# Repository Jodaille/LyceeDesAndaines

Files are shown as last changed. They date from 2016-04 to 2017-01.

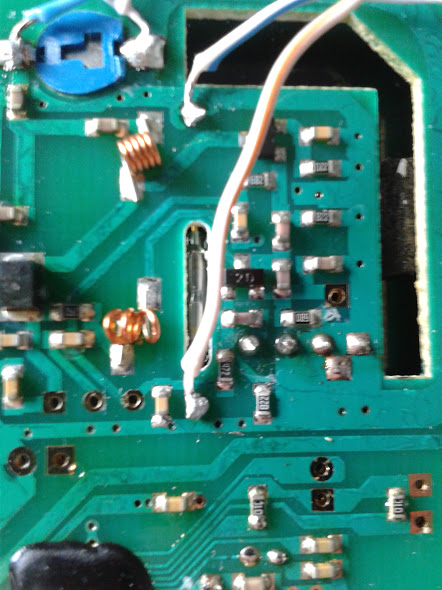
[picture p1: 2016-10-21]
JaugePluieInterruption/Soldered_wires_for_contact.jpg

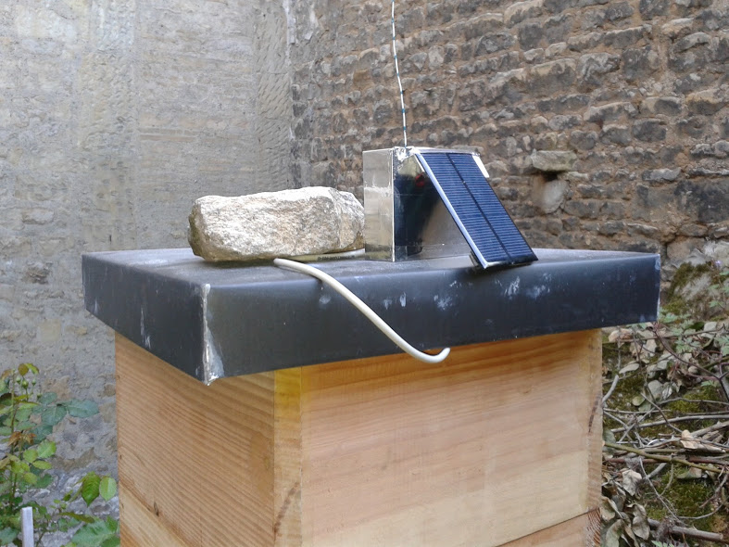
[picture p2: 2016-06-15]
Arduino_RF_mini_Solar_panel.jpg

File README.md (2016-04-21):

# Lycee Des Andaines

L'objectif est de connaître l'environnement extérieur et intérieur d'une ruche.

L'idée est de pouvoir anticiper au possible l'essaimage.

Arduino est choisi afin d'initier les élèves au développement logiciel,
à l'électricité, à l'électronique et à la mesure physique.

## Sketchs/programmes exemples

Nous avons besoin de connaître quelques facteurs environnementaux :

- température
- masse de la ruche
- activité de la ruche

Nous disposons de capteurs de type DS18B20.

La masse est estimée avec un capteur mesurant la pression exercée par la ruche
sur un liquide contenu dans des sachets étanches (type compote).

L'activité globale sera estimée à l'aide de capteurs infra-rouge placés
à l'entrée de la ruche.

## Difficultés (techniques) rencontrées

### Capteur de température

Thermomètre numérique DS18B20, version waterproof,
avec interface 1-Wire (One-wire).

### Compteur d'abeilles

Le compteur nécessite deux capteurs IR par couloir. (QRE1113 FSC SENSOR REFL 5MM PHOTOTRANS THRU)
Nous devons comparer le passage devant un capteur puis l'autre pour déduire s'il
s'agit d'une entrée ou d'une sortie.

La lecture des capteurs est assez rapide, elle effectue de nombreuses lectures
par secondes.

Pour une prote de ruche de près de 30cm, avec un couloir de 1cm de large, il
nous faudrait donc 60 capteurs IR.

Nous décidones de réduire cette porte, toutefois Arduino ne possède toujours
pas assez d'entrée. Nous décidons d'utiliser un/des multiplexeurs du type :
CD74HC4067

### Capteur de pression / mesure de l' évolution de la masse de la ruche

La précision du convertisseur ADC de l'Arduino est insuffisante,
nous décidons d'utiliser un convertisseur Analogique/Numérique ADS1015
avec une précision sur 12 bit à 3300 samples/seconde via I2C.

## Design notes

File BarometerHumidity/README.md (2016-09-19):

# Moniteur/enregistreur de l'environement de la ruche

Un Arduino Nano permet de relever la température, l'humidité extérieure,
la pression atmosphérique aux alentours de la ruche.

Deux capteurs de température DS18B20, un fixé au plancher devant
la porte d'entrée, l'autre sous le toit entre la grille et le couvre toit.

En attendant de pouvoir mesurer la hauteur des précipitations,
un capteur de chute de pluie est en test.

La plupart des capteurs sont reliés sur le bus I2C, correspondant
aux pins A4 et A5.

## Baromètre.

BMP 280 relié en I2C

## Température et humidité

Si7021 relié en I2C

## Capteur de chute de pluie

relié en A7

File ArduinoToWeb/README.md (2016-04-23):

# Connect Arduino to the Web with OpenWRT

## Requirements

- [x] Arduino Uno, Nano ...
- [x] OpenWRT Router [TL-WR703N Mod 64Mb](http://www.ebay.com/itm/181078954797)
- [x] a Webserver or a service

## Arduino talks to the Web

Arduino is linked to router by USB cable.

Read datas are written to serial (USB),
we use a [script](https://github.com/Jodaille/LyceeDesAndaines/blob/master/ArduinoToLinux/ReadArduinoSerial.sh) to read serial
port, do some string management, then play an HTTP GET query to a simple PHP script page on a remote server.

The script is launched on the router in a screen (GNU/Screen). So that process should not die when we kill current terminal session.

## Arduino test sketch

[LogTestToWeb.ino](https://github.com/Jodaille/LyceeDesAndaines/blob/master/ArduinoToLinux/LogTestToWeb/LogTestToWeb.ino) is a simple sketch that read then print some values every "interval" seconds (no delay) on the serial.

Each values are semicolumn separated.

## SHell script to read serial and push to the Web

[ReadArduinoSerial.sh](https://github.com/Jodaille/LyceeDesAndaines/blob/master/ArduinoToLinux/ReadArduinoSerial.sh) is launched on device /dev/ttyUSB0 (Nano)

## OpenWRT

Kernel modules to install, example:

    opkg update
    opkg install kmod-usb-serial-ch341

Modules for Arduino Nano with CH341 USB serial chip:

    kmod-usb-serial
    kmod-usb-serial-ch341
    kmod-usb-serial-cp210x

Tool to install:

    opkg install screen

[readUSB.sh](https://github.com/Jodaille/LyceeDesAndaines/blob/master/ArduinoToLinux/readUSB.sh) is a simple script that send output of serial port (/dev/ttyUSB0) to [ReadArduinoSerial.sh](https://github.com/Jodaille/LyceeDesAndaines/blob/master/ArduinoToLinux/ReadArduinoSerial.sh) for processing.

With screen you can have this process forever, that means it will not ended after your logout from terminal.

    screen -Sdm readArduino -s  /readUSB.sh

Next step will be to be able to start after the boot (crontab ?) and maybe to check that process exist unless relaunch it.

It could be nice if readUSB.sh could be detect the Arduino port.

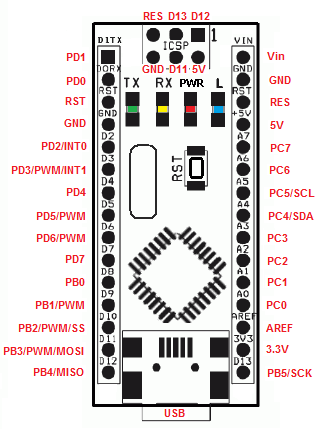
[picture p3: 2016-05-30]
ArduinoNano_pinout.png

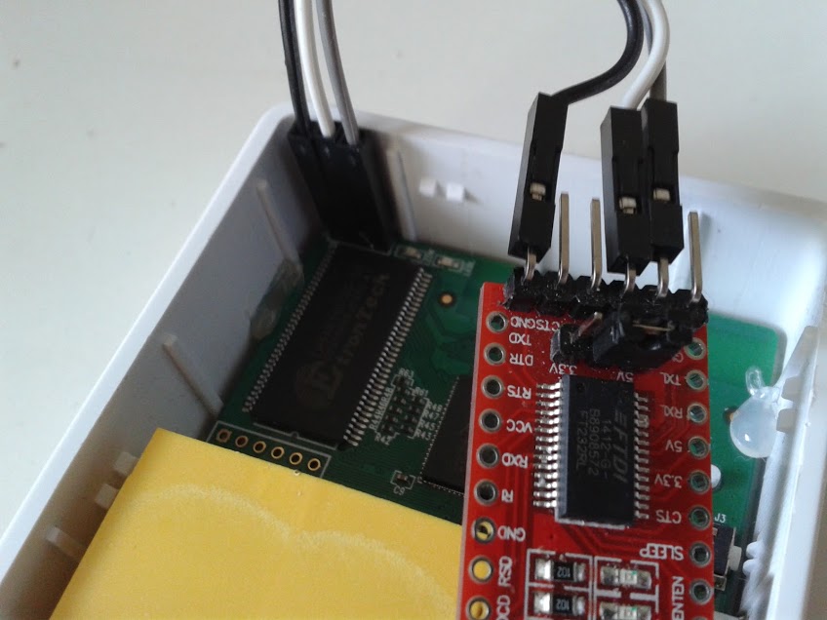
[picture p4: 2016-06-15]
GLiNet_FTDI_serial.jpg

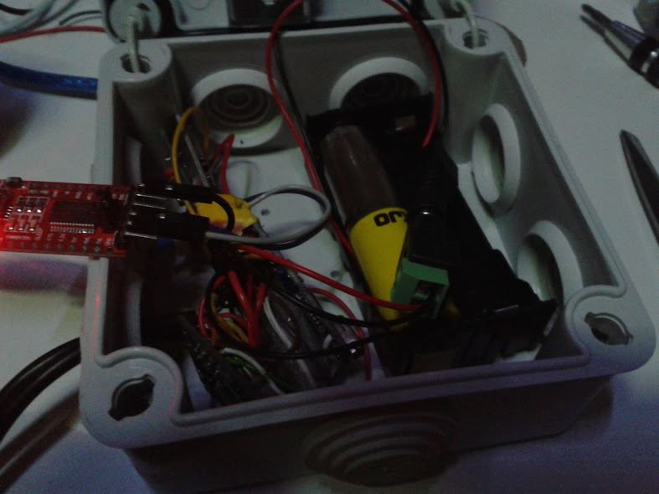
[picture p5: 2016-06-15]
Arduino_Logger.jpg

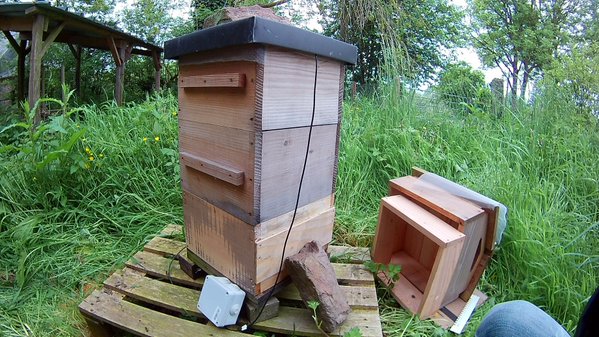
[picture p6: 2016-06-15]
Boitier_etanche.jpg

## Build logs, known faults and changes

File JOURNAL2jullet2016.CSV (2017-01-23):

id=13 | time=2016-06-25 16:50:09 | t1=17.94 | t2=18.88 | v=153 | milli=1414
id=13 | time=2016-06-25 16:50:41 | t1=18.06 | t2=19.13 | v=163 | milli=32332
id=13 | time=2016-06-25 16:51:12 | t1=18.19 | t2=19.44 | v=163 | milli=63223
id=13 | time=2016-06-25 16:51:43 | t1=18.81 | t2=19.94 | v=163 | milli=94112
id=13 | time=2016-06-25 16:52:15 | t1=19.56 | t2=20.88 | v=163 | milli=125002
id=13 | time=2016-06-25 16:52:46 | t1=19.81 | t2=21.06 | v=163 | milli=155892
id=13 | time=2016-06-25 16:53:18 | t1=19.88 | t2=21.13 | v=163 | milli=186784
id=13 | time=2016-06-25 16:53:49 | t1=19.94 | t2=21.06 | v=163 | milli=217675
id=13 | time=2016-06-25 16:54:20 | t1=19.94 | t2=21.00 | v=163 | milli=248570
id=13 | time=2016-06-25 16:54:52 | t1=19.94 | t2=20.88 | v=163 | milli=279462
id=13 | time=2016-06-25 16:55:23 | t1=20.00 | t2=20.81 | v=163 | milli=310353
id=13 | time=2016-06-25 16:55:55 | t1=20.13 | t2=20.75 | v=163 | milli=341244
id=13 | time=2016-06-25 16:56:26 | t1=20.25 | t2=20.69 | v=163 | milli=372133
id=13 | time=2016-06-25 16:56:58 | t1=20.44 | t2=20.63 | v=163 | milli=403025
id=13 | time=2016-06-25 16:57:29 | t1=20.56 | t2=20.63 | v=163 | milli=433916
id=13 | time=2016-06-25 16:58:00 | t1=20.63 | t2=20.44 | v=163 | milli=464811
id=13 | time=2016-06-25 16:58:32 | t1=20.69 | t2=20.38 | v=163 | milli=495702
id=13 | time=2016-06-25 16:59:03 | t1=20.69 | t2=20.25 | v=163 | milli=526594
id=13 | time=2016-06-25 16:59:35 | t1=20.63 | t2=20.13 | v=163 | milli=557484
id=13 | time=2016-06-25 17:00:06 | t1=20.63 | t2=20.06 | v=163 | milli=588374
id=13 | time=2016-06-25 17:00:37 | t1=20.63 | t2=19.94 | v=163 | milli=619265
id=13 | time=2016-06-25 17:01:09 | t1=20.56 | t2=19.81 | v=163 | milli=650157
id=13 | time=2016-06-25 17:01:40 | t1=20.50 | t2=19.75 | v=163 | milli=681047
id=13 | time=2016-06-25 17:02:12 | t1=20.50 | t2=19.63 | v=163 | milli=711943
id=13 | time=2016-06-25 17:02:43 | t1=20.44 | t2=19.50 | v=163 | milli=742834
id=13 | time=2016-06-25 17:03:15 | t1=20.38 | t2=19.38 | v=163 | milli=773725
id=13 | time=2016-06-25 17:03:46 | t1=20.38 | t2=19.25 | v=163 | milli=804614
id=13 | time=2016-06-25 17:04:17 | t1=20.38 | t2=19.19 | v=163 | milli=835506
id=13 | time=2016-06-25 17:04:49 | t1=20.25 | t2=19.13 | v=163 | milli=866397
id=13 | time=2016-06-25 17:05:20 | t1=20.25 | t2=19.13 | v=163 | milli=897288
id=13 | time=2016-06-25 17:05:52 | t1=20.25 | t2=19.13 | v=163 | milli=928183
id=13 | time=2016-06-25 17:06:23 | t1=20.25 | t2=19.00 | v=163 | milli=959075
id=13 | time=2016-06-25 17:06:54 | t1=20.31 | t2=18.88 | v=163 | milli=989965
id=13 | time=2016-06-25 17:07:26 | t1=20.31 | t2=18.88 | v=163 | milli=1020856
id=13 | time=2016-06-25 17:07:57 | t1=20.25 | t2=19.00 | v=163 | milli=1051748
id=13 | time=2016-06-25 17:08:29 | t1=20.19 | t2=19.06 | v=163 | milli=1082641
id=13 | time=2016-06-25 17:09:00 | t1=20.13 | t2=19.19 | v=163 | milli=1113533
id=13 | time=2016-06-25 17:09:32 | t1=20.19 | t2=19.38 | v=163 | milli=1144429
id=13 | time=2016-06-25 17:10:03 | t1=20.13 | t2=19.56 | v=163 | milli=1175322
id=13 | time=2016-06-25 17:10:34 | t1=20.06 | t2=19.63 | v=163 | milli=1206213
id=13 | time=2016-06-25 17:11:06 | t1=20.06 | t2=19.69 | v=163 | milli=1237104
id=13 | time=2016-06-25 17:11:37 | t1=20.13 | t2=19.69 | v=163 | milli=1267996
id=13 | time=2016-06-25 17:12:09 | t1=20.13 | t2=19.81 | v=163 | milli=1298889
id=13 | time=2016-06-25 17:12:40 | t1=20.13 | t2=19.81 | v=163 | milli=1329780
id=13 | time=2016-06-25 17:13:11 | t1=20.19 | t2=19.88 | v=163 | milli=1360677
id=13 | time=2016-06-25 17:13:43 | t1=20.19 | t2=19.81 | v=163 | milli=1391570
id=13 | time=2016-06-25 17:14:14 | t1=20.25 | t2=19.88 | v=163 | milli=1422461
id=13 | time=2016-06-25 17:14:46 | t1=20.25 | t2=19.81 | v=163 | milli=1453353
id=13 | time=2016-06-25 17:15:17 | t1=20.25 | t2=19.75 | v=163 | milli=1484244
id=13 | time=2016-06-25 17:15:48 | t1=20.25 | t2=19.75 | v=163 | milli=1515137
id=13 | time=2016-06-25 17:16:20 | t1=20.25 | t2=19.69 | v=163 | milli=1546028
id=13 | time=2016-06-25 17:16:51 | t1=20.25 | t2=19.56 | v=163 | milli=1576920
id=13 | time=2016-06-25 17:17:23 | t1=20.25 | t2=19.56 | v=163 | milli=1607817
id=13 | time=2016-06-25 17:17:54 | t1=20.25 | t2=19.50 | v=163 | milli=1638709
id=13 | time=2016-06-25 17:18:26 | t1=20.19 | t2=19.44 | v=163 | milli=1669599
id=13 | time=2016-06-25 17:18:57 | t1=20.19 | t2=19.38 | v=163 | milli=1700492
id=13 | time=2016-06-25 17:19:28 | t1=20.13 | t2=19.31 | v=163 | milli=1731384
id=13 | time=2016-06-25 17:20:00 | t1=20.06 | t2=19.19 | v=163 | milli=1762276
id=13 | time=2016-06-25 17:20:31 | t1=20.00 | t2=19.13 | v=163 | milli=1793168
id=13 | time=2016-06-25 17:21:03 | t1=20.00 | t2=19.13 | v=163 | milli=1824078
id=13 | time=2016-06-25 17:21:34 | t1=20.00 | t2=19.06 | v=163 | milli=1854972
id=13 | time=2016-06-25 17:22:05 | t1=20.00 | t2=19.00 | v=163 | milli=1885867
id=13 | time=2016-06-25 17:22:37 | t1=20.00 | t2=18.94 | v=163 | milli=1916761
id=13 | time=2016-06-25 17:23:08 | t1=20.00 | t2=18.81 | v=163 | milli=1947657
id=13 | time=2016-06-25 17:23:40 | t1=20.00 | t2=18.75 | v=163 | milli=1978550
id=13 | time=2016-06-25 17:24:11 | t1=20.00 | t2=18.69 | v=163 | milli=2009445
id=13 | time=2016-06-25 17:24:43 | t1=19.94 | t2=18.63 | v=163 | milli=2040345
id=13 | time=2016-06-25 17:25:14 | t1=19.94 | t2=18.56 | v=163 | milli=2071239
id=13 | time=2016-06-25 17:25:45 | t1=20.00 | t2=18.56 | v=163 | milli=2102133
id=13 | time=2016-06-25 17:26:17 | t1=20.00 | t2=18.50 | v=163 | milli=2133028
id=13 | time=2016-06-25 17:26:48 | t1=20.06 | t2=18.44 | v=163 | milli=2163923
id=13 | time=2016-06-25 17:27:20 | t1=20.00 | t2=18.38 | v=163 | milli=2194818
id=13 | time=2016-06-25 17:27:51 | t1=20.00 | t2=18.38 | v=163 | milli=2225711
id=13 | time=2016-06-25 17:28:22 | t1=19.94 | t2=18.38 | v=163 | milli=2256612
id=13 | time=2016-06-25 17:28:54 | t1=19.88 | t2=18.38 | v=163 | milli=2287506
id=13 | time=2016-06-25 17:29:25 | t1=19.81 | t2=18.31 | v=163 | milli=2318399
id=13 | time=2016-06-25 17:29:57 | t1=19.81 | t2=18.31 | v=163 | milli=2349295
id=13 | time=2016-06-25 17:30:28 | t1=19.75 | t2=18.31 | v=163 | milli=2380190
id=13 | time=2016-06-25 17:30:59 | t1=19.69 | t2=18.25 | v=163 | milli=2411084
id=13 | time=2016-06-25 17:31:31 | t1=19.69 | t2=18.25 | v=163 | milli=2441977
id=13 | time=2016-06-25 17:32:02 | t1=19.63 | t2=18.19 | v=163 | milli=2472878
id=13 | time=2016-06-25 17:32:34 | t1=19.56 | t2=18.19 | v=163 | milli=2503773
id=13 | time=2016-06-25 17:33:05 | t1=19.56 | t2=18.19 | v=163 | milli=2534666
id=13 | time=2016-06-25 17:33:36 | t1=19.50 | t2=18.19 | v=163 | milli=2565561
id=13 | time=2016-06-25 17:34:08 | t1=19.44 | t2=18.19 | v=163 | milli=2596457
id=13 | time=2016-06-25 17:34:39 | t1=19.44 | t2=18.19 | v=163 | milli=2627350
id=13 | time=2016-06-25 17:35:11 | t1=19.38 | t2=18.13 | v=163 | milli=2658245
id=13 | time=2016-06-25 17:35:42 | t1=19.38 | t2=18.06 | v=163 | milli=2689139
id=13 | time=2016-06-25 17:36:13 | t1=19.31 | t2=18.06 | v=163 | milli=2720039
id=13 | time=2016-06-25 17:36:45 | t1=19.31 | t2=18.00 | v=163 | milli=2750942
id=13 | time=2016-06-25 17:37:16 | t1=19.31 | t2=18.00 | v=163 | milli=2781836
id=13 | time=2016-06-25 17:37:48 | t1=19.25 | t2=17.94 | v=163 | milli=2812732
id=13 | time=2016-06-25 17:38:19 | t1=19.31 | t2=18.00 | v=163 | milli=2843626
id=13 | time=2016-06-25 17:38:50 | t1=19.44 | t2=18.00 | v=163 | milli=2874519
id=13 | time=2016-06-25 17:39:22 | t1=19.50 | t2=18.00 | v=163 | milli=2905415
id=13 | time=2016-06-25 17:39:53 | t1=19.44 | t2=18.06 | v=163 | milli=2936315
id=13 | time=2016-06-25 17:40:25 | t1=19.31 | t2=18.06 | v=163 | milli=2967208
id=13 | time=2016-06-25 17:40:56 | t1=19.25 | t2=18.06 | v=163 | milli=2998103
id=13 | time=2016-06-25 17:41:27 | t1=19.25 | t2=18.06 | v=163 | milli=3028998
id=13 | time=2016-06-25 17:41:59 | t1=19.19 | t2=18.13 | v=163 | milli=3059893
id=13 | time=2016-06-25 17:42:30 | t1=19.19 | t2=18.06 | v=163 | milli=3090786
id=13 | time=2016-06-25 17:43:02 | t1=19.13 | t2=18.06 | v=163 | milli=3121681
id=13 | time=2016-06-25 17:43:33 | t1=19.13 | t2=18.06 | v=163 | milli=3152581
id=13 | time=2016-06-25 17:44:04 | t1=19.13 | t2=18.00 | v=163 | milli=3183475
id=13 | time=2016-06-25 17:44:36 | t1=19.13 | t2=17.94 | v=163 | milli=3214370
id=13 | time=2016-06-25 17:45:07 | t1=19.13 | t2=17.94 | v=163 | milli=3245266
id=13 | time=2016-06-25 17:45:39 | t1=19.13 | t2=17.88 | v=163 | milli=3276159
id=13 | time=2016-06-25 17:46:10 | t1=19.19 | t2=17.88 | v=163 | milli=3307053
id=13 | time=2016-06-25 17:46:41 | t1=19.13 | t2=17.88 | v=163 | milli=3337948
id=13 | time=2016-06-25 17:47:13 | t1=19.06 | t2=17.88 | v=163 | milli=3368848
id=13 | time=2016-06-25 17:47:44 | t1=19.00 | t2=17.88 | v=163 | milli=3399742
id=13 | time=2016-06-25 17:48:16 | t1=19.00 | t2=17.81 | v=163 | milli=3430636
id=13 | time=2016-06-25 17:48:47 | t1=18.94 | t2=17.81 | v=163 | milli=3461532
id=13 | time=2016-06-25 17:49:18 | t1=18.94 | t2=17.88 | v=163 | milli=3492425
id=13 | time=2016-06-25 17:49:50 | t1=18.94 | t2=17.81 | v=163 | milli=3523319
id=13 | time=2016-06-25 17:50:21 | t1=18.94 | t2=17.81 | v=163 | milli=3554215
id=13 | time=2016-06-25 17:50:53 | t1=18.94 | t2=17.81 | v=163 | milli=3585129
id=13 | time=2016-06-25 17:51:24 | t1=18.88 | t2=17.81 | v=163 | milli=3616022
id=13 | time=2016-06-25 17:51:55 | t1=18.94 | t2=17.88 | v=163 | milli=3646929
id=13 | time=2016-06-25 17:52:27 | t1=18.94 | t2=17.88 | v=163 | milli=3677824
id=13 | time=2016-06-25 17:52:58 | t1=18.94 | t2=17.88 | v=163 | milli=3708718
id=13 | time=2016-06-25 17:53:30 | t1=18.88 | t2=17.94 | v=163 | milli=3739612
id=13 | time=2016-06-25 17:54:01 | t1=18.88 | t2=18.00 | v=163 | milli=3770507
id=13 | time=2016-06-25 17:54:32 | t1=18.88 | t2=18.06 | v=163 | milli=3801402
id=13 | time=2016-06-25 17:55:04 | t1=18.88 | t2=18.13 | v=163 | milli=3832301
id=13 | time=2016-06-25 17:55:35 | t1=18.81 | t2=18.19 | v=163 | milli=3863196
id=13 | time=2016-06-25 17:56:07 | t1=18.81 | t2=18.25 | v=163 | milli=3894091
id=13 | time=2016-06-25 17:56:38 | t1=18.81 | t2=18.38 | v=163 | milli=3924985
id=13 | time=2016-06-25 17:57:09 | t1=18.81 | t2=18.50 | v=163 | milli=3955879
id=13 | time=2016-06-25 17:57:41 | t1=18.81 | t2=18.63 | v=163 | milli=3986775
id=13 | time=2016-06-25 17:58:12 | t1=18.81 | t2=18.69 | v=163 | milli=4017669
id=13 | time=2016-06-25 17:58:44 | t1=18.81 | t2=18.75 | v=163 | milli=4048568
id=13 | time=2016-06-25 17:59:15 | t1=18.81 | t2=18.81 | v=163 | milli=4079463
id=13 | time=2016-06-25 17:59:47 | t1=18.81 | t2=18.81 | v=163 | milli=4110358
id=13 | time=2016-06-25 18:00:18 | t1=18.81 | t2=18.88 | v=163 | milli=4141253
id=13 | time=2016-06-25 18:00:49 | t1=18.81 | t2=18.88 | v=163 | milli=4172146
id=13 | time=2016-06-25 18:01:21 | t1=18.75 | t2=18.88 | v=163 | milli=4203042
id=13 | time=2016-06-25 18:01:52 | t1=18.81 | t2=18.88 | v=163 | milli=4233937
id=13 | time=2016-06-25 18:02:24 | t1=18.81 | t2=18.88 | v=163 | milli=4264835
id=13 | time=2016-06-25 18:02:55 | t1=18.81 | t2=18.88 | v=163 | milli=4295731
id=13 | time=2016-06-25 18:03:26 | t1=18.81 | t2=18.88 | v=163 | milli=4326625
id=13 | time=2016-06-25 18:03:58 | t1=18.81 | t2=18.88 | v=163 | milli=4357520
id=13 | time=2016-06-25 18:04:29 | t1=18.81 | t2=18.81 | v=163 | milli=4388414
id=13 | time=2016-06-25 18:05:01 | t1=18.88 | t2=18.75 | v=163 | milli=4419309
id=13 | time=2016-06-25 18:05:32 | t1=18.88 | t2=18.69 | v=163 | milli=4450205
id=13 | time=2016-06-25 18:06:04 | t1=18.88 | t2=18.69 | v=163 | milli=4481102
id=13 | time=2016-06-25 18:06:35 | t1=18.88 | t2=18.63 | v=163 | milli=4511998
id=13 | time=2016-06-25 18:07:06 | t1=18.81 | t2=18.63 | v=163 | milli=4542894
id=13 | time=2016-06-25 18:07:38 | t1=18.81 | t2=18.63 | v=163 | milli=4573787
id=13 | time=2016-06-25 18:08:09 | t1=18.81 | t2=18.69 | v=163 | milli=4604681
id=13 | time=2016-06-25 18:08:41 | t1=18.81 | t2=18.69 | v=163 | milli=4635576
id=13 | time=2016-06-25 18:09:12 | t1=18.81 | t2=18.69 | v=163 | milli=4666472
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

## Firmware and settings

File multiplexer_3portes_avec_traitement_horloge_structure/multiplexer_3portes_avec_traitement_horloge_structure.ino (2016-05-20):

//int pinLed = 13; //led de arduino
int entrees =0; //pour mettre les compteurs à 0 au démarrage
int sorties =0;

//variable pour compter les passages vrai devant A près de la ruche - B près de la sortie
int passageA =0;
int passageB =0;

//variable pour compter les erreurs abeilles qui stationnent ou qui se suivent
int erreur =0;

//variable pour compter  1par boucle quand A/B est niveau bas
int countA = 0;
int countB = 0;

//chrono A et chronoB sont 2 variables longues pour stocker les temps de passage devant les détecteurs A et B
unsigned long chronoA=0;
unsigned long chronoB=0;

/**
 * Tiny RTC module
 * module horloge
 *
 * DS1307 pour bus I2C
 * avec batterie au lithium CR1225
 *
 * Le port I2C de l'Arduino est situé
 * sur les pin A4 et A5
 *
 * Analog pin A5 <-> SCL
 * Analog pin A4 <-> SDA
 */

#include <Wire.h>
/**
 * Nous utilisons la librairie RTClib
 * cf: https://github.com/adafruit/RTClib/archive/master.zip
 * à installer dans le répertoire libraries
 * du répertoire de sketchs
 */
#include "RTClib.h"
RTC_DS1307 RTC;
// pour ajuster l'heure changer false en : true
bool definirHeure = true;

//branchement des sorties du multiplexeur qui permettent de récupérer les données des 16 entrées (4X4)
int s0 = 6;
int s1 = 7;
int s2 = 8;
int s3 = 9;

int SIG_pin = 10; //connexion du multiplexeur à l'arduino

#define NBPORTES 3  // à adapter au nombre de portes connectées, jusqu'à 8
#define NBCAPTEURS 2 // 2 capteurs par porte

#define nbPortes 8
/**
 * structure Porte
 * permet d'organiser les infos par porte
 */
struct Porte {
    int  pinsortie;
    int  pinentree;
    long tempsLectureEntree;
    long tempsLectureSortie;
    int  lectureEntree;
    int  lectureSortie;
    int  compteurEntree;
    int  compteurSortie;
} portes[nbPortes];




void setup() {
// initialisation porte 0
portes[0].pinentree = 0;
portes[0].pinsortie = 1;
portes[0].tempsLectureEntree = 0;
portes[0].tempsLectureSortie = 0;
portes[0].lectureEntree = 1; // 1 quand rien ne coupe le faisceau
portes[0].lectureSortie = 1;
portes[0].compteurEntree = 0;
portes[0].compteurSortie = 0;

// initialisation porte 1
portes[1].pinentree = 2;
portes[1].pinsortie = 3;
portes[1].tempsLectureEntree = 0;
portes[1].tempsLectureSortie = 0;
portes[1].lectureEntree = 1;
portes[1].lectureSortie = 1;
portes[1].compteurEntree = 0;
portes[1].compteurSortie = 0;

// initialisation porte 2
portes[2].pinentree = 4;
portes[2].pinsortie = 5;
portes[2].tempsLectureEntree = 0;
portes[2].tempsLectureSortie = 0;
portes[2].lectureEntree = 1;
portes[2].lectureSortie = 1;
portes[2].compteurEntree = 0;
portes[2].compteurSortie = 0;

  // put your setup code here, to run once:
  pinMode(s0, OUTPUT);
  pinMode(s1, OUTPUT);
  pinMode(s2, OUTPUT);
  pinMode(s3, OUTPUT);

  digitalWrite(s0, LOW);
  digitalWrite(s1, LOW);
  digitalWrite(s2, LOW);
  digitalWrite(s3, LOW);

  Serial.begin(9600);
  Serial.println("Start");

   //zone horloge
    Wire.begin();
    RTC.begin();
  if (! RTC.isrunning())
  {
    Serial.println("RTC ne fonctionne pas!");
  }

  if(definirHeure)
  {
      // la ligne suivante permet d'ajuster la date & l'heure
      // à la date de compilation du sketc
      RTC.adjust(DateTime(__DATE__, __TIME__));
  }

}

void loop() {
  // programme qui tourne en boucle

    //pinMode(pinLed, OUTPUT); //on éteint la led de arduino au démarrage
    unsigned long temps =millis();
    for (int numPorte=0; numPorte<NBPORTES; numPorte++)
    {
        int channelEntree = portes[numPorte].pinentree;
        portes[numPorte].lectureEntree = readMux(channelEntree);

        int channelSortie = portes[numPorte].pinsortie;
        portes[numPorte].lectureSortie = readMux(channelSortie);

        //on compte le nombre de passage devant le capteur, passé à 0
        if(portes[numPorte].lectureEntree == 0)
        {
            portes[numPorte].compteurEntree++;
        }

        if(portes[numPorte].lectureSortie == 0)
        {
            portes[numPorte].compteurSortie++;
        }

        // si nous n'avons plus de passage (capteur à 1)
        if(portes[numPorte].lectureEntree == 1)
        {
            // et que nousa avons eu plusieurs lecture positive
            if(portes[numPorte].compteurEntree > 1)
            {
                // alors nous incrémentons le passage
                passageA++;
                // et remettons notre compteur à 0
                portes[numPorte].compteurEntree = 0;
                // nous pouvons stocker le temps au passage:
                portes[numPorte].tempsLectureEntree = temps;
            }
        }
        // idem pour la porte pres de la sortie
        // si nous n'avons plus de passage (capteur à 1)
        if(portes[numPorte].lectureSortie == 1)
        {
            // et que nousa avons eu plusieurs lecture positive
            if(portes[numPorte].compteurSortie > 1)
            {
                // alors nous incrémentons le passage
                passageB++;
                // et remettons notre compteur à 0
                portes[numPorte].compteurSortie = 0;
                // nous pouvons stocker le temps au passage:
                portes[numPorte].tempsLectureSortie = temps;
            }
        }

        // verification du temps de passage :
        if(portes[numPorte].tempsLectureEntree > portes[numPorte].tempsLectureSortie)
        {
            // passée devant capteur entree avant celui de sortie: elle est sortie
            sorties++;

        }
        else
        {
            entrees++;
        }
    }
}

//readMux est la fonction qui lit chaque capteur appelé par readMux

int readMux(int channel){
  int controlPin[] = {s0, s1, s2, s3};

  int muxChannel[16][4]={
    {0,0,0,0}, //channel 0
    {1,0,0,0}, //channel 1
    {0,1,0,0}, //channel 2
    {1,1,0,0}, //channel 3
    {0,0,1,0}, //channel 4
    {1,0,1,0}, //channel 5
    {0,1,1,0}, //channel 6
    {1,1,1,0}, //channel 7
    {0,0,0,1}, //channel 8
    {1,0,0,1}, //channel 9
    {0,1,0,1}, //channel 10
    {1,1,0,1}, //channel 11
    {0,0,1,1}, //channel 12
    {1,0,1,1}, //channel 13
    {0,1,1,1}, //channel 14
    {1,1,1,1}, //channel 15
  };

   //loop through the 4 sig
  for(int i = 0; i < 4; i ++){
    digitalWrite(controlPin[i], muxChannel[channel][i]);
  }

  //read the value at the SIG pin
  int val = digitalRead(SIG_pin);

  //return the value
  return val;

}

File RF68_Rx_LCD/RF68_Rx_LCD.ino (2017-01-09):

/**
 * Exemple basic de réception avec transmetteurs
 * de type RFM69
 * 
 * source:
 * Simple RFM12B wireless demo - Receiver - no ack
 * Glyn Hudson openenergymonitor.org GNU GPL V3 12/4/12
 * Credit to JCW from Jeelabs.org for RFM12 
 * 
 * voir aussi: 
 * https://www.mysensors.org/build/connect_radio#wiring-the-rfm69-radio
 */

#define RF69_COMPAT 1  // 1 pour RFM69CW ou 0 pour RFM12B
#include <JeeLib.h>

#include <LCD.h>
#include <LiquidCrystal_I2C.h>

#define I2C_ADDR    0x27  // Defini adrese I2C pour PCF8574T (ecran)
#define BACKLIGHT_PIN  3
#define En_pin  2
#define Rw_pin  1
#define Rs_pin  0
#define D4_pin  4
#define D5_pin  5
#define D6_pin  6
#define D7_pin  7

#define  LED_OFF  1
#define  LED_ON  0

/*-----( Declare objects )-----*/  
LiquidCrystal_I2C  lcd(I2C_ADDR,En_pin,Rw_pin,Rs_pin,D4_pin,D5_pin,D6_pin,D7_pin);

#define myNodeID 30          // node ID du Rx (range 0-30) 
#define network     210      // groupe du reseau (peut être entre 1-250), le même que l'emeteur
/**
 * Frequences du RF12B/RFM69 peut être: 
 * RF12_433MHZ, RF12_868MHZ ou RF12_915MHZ.  
 * fonction de la frequence du module
*/
#define RF_freq RF12_868MHZ

// Structure contenant les données, doivent être identiques entre emetteur et recepteur
typedef struct { int power1, power2, power3, battery; } PayloadTX;
PayloadTX emontx;  

const int emonTx_NodeID=10; // Nodeid / identifiant de l'emetteur

void setup() {
  
  rf12_initialize(myNodeID,RF_freq,network);   //Initialise RFM69 avec parametres precedents  
  Serial.begin(57600); 
  Serial.println("RF12B demo Receiver - Simple demo"); 

  lcd.begin (16,2); // pour LCD de 16 caracteres x 2 lignes
  lcd.setBacklightPin(3,POSITIVE);
  lcd.setBacklight(HIGH);

  lcd.home (); // place le curseur en 0,0 (premier caractere, premiere ligne)
  lcd.setCursor (3,0);
  lcd.print(myNodeID); // affiche le node id (ici: 30)

 Serial.print("Node: "); 
 Serial.print(myNodeID); 
 Serial.print(" Freq: "); 
 if (RF_freq == RF12_433MHZ) Serial.print("433Mhz");
 if (RF_freq == RF12_868MHZ) Serial.print("868Mhz");
 if (RF_freq == RF12_915MHZ) Serial.print("915Mhz");  
 Serial.print(" Network: "); 
 Serial.println(network);
}

void loop() {
  
 if (rf12_recvDone()){ // si reception
  if (rf12_crc == 0 && (rf12_hdr & RF12_HDR_CTL) == 0) {

    lcd.home (); // retour à 0 du LCD

    int node_id = (rf12_hdr & 0x1F); //extraction du nodeID depuis payload

    lcd.print("node:");
    lcd.print(node_id);// Affichage du nodeid de l'emetteur sur le LCD

    if (node_id == emonTx_NodeID)  {    //est-ce bien l'id de notre emetteur?
        emontx=*(PayloadTX*) rf12_data; // Extraction des données reçues de payload 
       Serial.print("power1: "); Serial.println(emontx.power1); 
       Serial.print("power2: "); Serial.println(emontx.power2); 
       Serial.print("power3: "); Serial.println(emontx.power3); 
       Serial.print("battery: "); Serial.println(emontx.battery);

       lcd.setCursor (0,1);       // on passe à la deuxieme ligne du LCD
       lcd.print(emontx.battery); // on affiche la valeur battery du struct
       Serial.println("  "); 
  }
 }
}
}

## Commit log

2016-01-19 scan des adresses des capteurs DS18B20
2016-01-19 ajout exemple de lecture un capteur DS18B20
2016-01-22 correction definition heure + commentaire lib RTClib
    [TinyRtcPetiteHorloge.ino]
2016-05-02 change pin to D2 + comment
2016-05-03 add first temperature sensor
2016-05-05 add fritzing
    [Jobee.fzz]
2016-05-06 two sensors rucheA
2016-05-22 deplacement dans ArduinoToWeb
2016-05-24 Jeelabs bandgap battery voltage measurement
2016-06-02 first work of 8 doors for bee counter with LDR
    [BeeCounter.fzz]
2016-06-02 Bee counter PCB routing validated
    [BeeCounter.fzz]
2016-06-09 reception temperature ajout barometre et id
2016-06-15 add voltage to log
2016-06-23 add byte voltage example
2016-07-05 read Arduino serial output send to Emoncms
2016-09-04 fetch image from ip camera
2016-09-04 three temperature sensors ds18b20
2016-10-20 add TSL2561 light/luminosity sensor
2016-10-20 add BMP barometric pressure sensor
2016-10-20 add Si7021 humidity sensor
2016-10-20 add reading of rainfall sensor
2016-10-21 add rain gauge with interrupt and INPUT_PULLUP
2016-10-21 add rain gauge pictures wires and removed contacts
2016-10-23 add Raingauge interrupt and counter
2016-11-13 tentative de traduction FR
2017-01-09 add RF69 openenergymonitor sample
2017-01-23 journal du 2 juillet
    [JOURNAL2jullet2016.CSV]
